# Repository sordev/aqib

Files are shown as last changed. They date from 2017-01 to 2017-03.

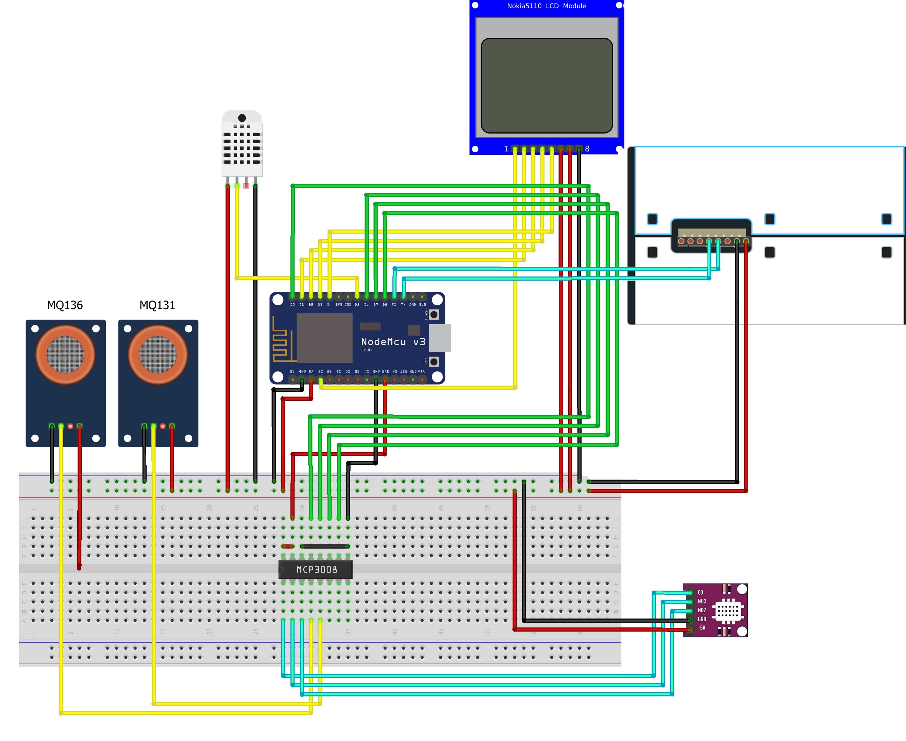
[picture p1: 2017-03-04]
fritzing/aqib_bb.jpg

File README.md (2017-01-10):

# АЧИЛ буюу Агаарын Чанарын Индекс тодорхойлогч Лонх 
(English Readers Please See Below)
АЧИЛ нь агаарын чанарыг тодорхойлох төхөөрөмж бөгөөд хамгийн гол нь хямд зардлаар боломжийн агаарын чанар тодорхойлох төхөөрөмж бий болгохын тулд хийгдсэн. Энэхүү код нь нээлттэй эхийнх ба бусад төрөл бүрийн нээлттэй эхээс жишээ авч бүтээгдсэн болно.

### АЧИЛ нь дараах зүйлсийг тодорхойлно.
  - PM2.5 болон PM10 тоосонцор.
  - SO2, O3, NO2, CO, NH3 химийн нэгдлүүд
  - Орчны температур, чийгшил

### АЧИЛ -н боломжууд.
  - WIFI модуль ашиглан интернэтээр дамжуулан мэдээллээ сервер дээр хадгалах

### Шаардлагатай сэлбэгүүд.
https://docs.google.com/spreadsheets/d/11MSpzdKqcEXNcD25FfU-qca580eOnAqrInOi8nA_Huc/edit?usp=sharing

### АЧИЛ -г бүтээх.
Дараах линкээр орж хэрхэн хийх талаар дэлгэрэнгүй мэдээлэл аваарай.

### Суулгац
Ардиуно https://www.arduino.cc/en/Main/Software -г татан авч ашиглана. Ашиглах сангууд
- Wire.h
- SPI.h
- LiquidCrystal.h
- DHT

### Хэрэглээ
- utaa.mn сайттай холбогдож өөрийн төхөөржийг бүртгүүлж нэвтрэх түлхүүр авна.
- Ардиуно руу байршуулахын өмнө өөрийн ВайФай -н холболтын мэдээлэл болон utaa.mn -с авсан түлхүүрийг оруулж өгнө. Холболт амжилттай хийгдвэл дэлгэц дээр мэдээлэл гарна.
- Төхөөрөмж амжилттай ажиллаж байвал дэлгэц дээр тоон үзүүлэлтүүд харагдах ба харагдаж байгаа тоон үзүүлэлтүүдийг сервер лүү автоматаар илгээж эхлэнэ. Төхөөрөмж нь эхний 24 - 48 цаг сенсор шатаалт явагдах бөгөөд түүнээс хойш үнэн бодит заах магадлалтай болно.

# AQIB Air Quality Index Bottle
AQIB is cheap solution for AQI sensor. Based on arduino and various sensors.

# AQIB can sense following
- PM2.5 and PM10 
- SO2, O3, NO2, CO and NH3 chemicals
- Temperature and humidity

# AQIB Features
- Will collect data and send to main server

# Required PARTS
https://docs.google.com/spreadsheets/d/11MSpzdKqcEXNcD25FfU-qca580eOnAqrInOi8nA_Huc/edit?usp=sharing

# How to build?

# Install
Visit https://www.arduino.cc/en/Main/Software for software. Clone code to your local. Install/Add following librarires
- Wire.h
- SPI.h
- LiquidCrystal.h
- DHT
Compline and upload to Arduino via software.

# Usage
- Ask utaa.mn for API Key
- Change variables inside code with your WiFi connection username/password, Update API Key with your own Key which is provided by utaa.mn
- If AQIB working and connected to WiFi you'll see information on screen, After succesful connection AQIB will show data on screen and will start sending data to server. Sensors requires to be burned out for at least 24-48 hours for good result.

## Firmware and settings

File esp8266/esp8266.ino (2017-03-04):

#include <SPI.h>

// Nokia 5110 LCD Libraries
// https://github.com/baghayi/Nokia_5110
#include "Nokia_5110.h"
#define RST 10 //s3 gpio10
#define CE 5 //d1 gpio5
#define DC 4 //d2 gpio4
#define DIN 0 //d3 gpio0
#define CLK 2 //d3 gpio2
Nokia_5110 lcd = Nokia_5110(RST, CE, DC, DIN, CLK);

// https://www.dfrobot.com/wiki/index.php/PM2.5_laser_dust_sensor_SKU:SEN0177
//******************************
//*Abstract: Read value of PM1,PM2.5 and PM10 of air quality
//
//*Version：V3.1
//*Author：Zuyang @ HUST
//*Modified by Cain for Arduino Hardware Serial port compatibility
//*Date：March.25.2016
//******************************
#include <Arduino.h>
#define LENG 31 //0x42 + 31 bytes equal to 32 bytes
unsigned char buf[LENG];

int PM1Value = 0; //define PM1.0 value of the air detector module
int PM25Value = 0; //define PM2.5 value of the air detector module
int PM10Value = 0; //define PM10 value of the air detector module

#include <ESP8266WiFi.h>
const char ssid[] = "devsor";
const char pass[] = "97070767";
const char api_url[] = "api.utaa.mn";
const char api_key[] = "3aa18dbe7df6844974e199e327c5c30e";
const char unwiredlabs_key[] = "918092cf2502c3";
const int interval = 60000; // 60000 = 1min
unsigned long startTime;
int tries = 0;
byte mac[6];

// Include DHT LIbrary
// DHT Library from https://github.com/adafruit/DHT-sensor-library required https://github.com/adafruit/Adafruit_Sensor
#include <DHT.h>
#define DHTPIN 14 //d5 gpio14
#define DHTTYPE DHT22
DHT dht(DHTPIN, DHTTYPE);
#include <DHT_U.h>
float humidity = 0;
float temp = 0;

// Include mcp3008 library ADC
// https://github.com/nodesign/MCP3008
#include <MCP3008.h>
#define CLOCK_PIN 16 //d0 gpio16
#define MISO_PIN 12 //d6 (mcp3008-Dout) gpio12
#define MOSI_PIN 13 //d7 (mcp3008-Din) gpio13
#define CS_PIN 15 //d8 (mcp3008-CS) gpio15
MCP3008 adc(CLOCK_PIN, MOSI_PIN, MISO_PIN, CS_PIN); //Setup mcp3008

// Analog reads
int co;
int nh3;
int no2;
int so2;
int o3; 

void setup(void)
{
  Serial.begin(9600);
  Serial.setTimeout(1500);    //set the Timeout to 1500ms, longer than the data transmission periodic time of the sensor
  setupSensor();
  ESP.wdtDisable(); // Disable Watchdog
  ESP.wdtEnable(WDTO_8S); // Enabling Watchdog
}

void loop(void)
{
  co = adc.readADC(0);
  nh3 = adc.readADC(1);
  no2 = adc.readADC(2);
  so2 = adc.readADC(3);
  o3 = adc.readADC(4);
  lcd.clear();
  lcd.println("CO: " + (String)co);
  lcd.println("NH3: " + (String)nh3);
  lcd.println("NO2: " + (String)no2);
  lcd.println("SO2: " + (String)so2);
  lcd.println("O3: " + (String)o3);
  delay(2000);

  humidity = dht.readHumidity();
  temp = dht.readTemperature();
  lcd.clear();
  lcd.println("Humi: " + (String)humidity + "%");
  lcd.println("Temp: " + (String)temp + "C");
  delay(2000);

  if (Serial.find(0x42)) {  //start to read when detect 0x42
    Serial.readBytes(buf, LENG);
    if (buf[0] == 0x4d) {
      if (checkValue(buf, LENG)) {
        PM1Value = transmitPM1(buf); //count PM1.0 value of the air detector module
        PM25Value = transmitPM25(buf); //count PM2.5 value of the air detector module
        PM10Value = transmitPM10(buf); //count PM10 value of the air detector module
      }
    }
  }

  lcd.clear();
  lcd.println("PM in ug/m3");
  lcd.println(" ");
  lcd.println("PM 1.0: " + (String)PM1Value);
  lcd.println("PM 2.5: " + (String)PM25Value);
  lcd.println("PM 10: " + (String)PM10Value);
  delay(2000);

  if (WiFi.status() == WL_CONNECTED) {
    //only send data after interval passed
    if (millis()-startTime > interval) {
      updateApi(
      "pm1=" + (String)PM1Value + 
      "&pm25=" + (String)PM25Value + 
      "&pm10=" + (String)PM10Value +       
      "&co=" + (String)co + 
      "&nh3=" + (String)nh3 + 
      "&no2=" + (String)no2 + 
      "&so2=" + (String)so2 + 
      "&o3=" + (String)o3 + 
      "&humidity=" + (String)humidity + 
      "&temperature=" + (String)temp
      );
      // Reset Timer
      startTime = millis();
      delay(3000);
    }
  }

  ESP.wdtFeed(); // Reset the WatchDog
}

boolean connectWiFi() {
  if (WiFi.status() == WL_CONNECTED) {
    lcd.clear();
    lcd.println("Connected WiFi:");
    lcd.println((String)ssid);
    startTime = millis(); // Start counting only when WiFi connected;
    delay(3000);
    return true;
  } else {
    WiFi.begin(ssid, pass);
    while (WiFi.status() != WL_CONNECTED || tries  < 4) {
      tries++;
      lcd.clear();
      lcd.println("Connecting:");
      lcd.println((String)ssid);
      lcd.println("Tries:" + String(tries));
      delay(1000);
    }
    lcd.println("Can't connect:");
    lcd.println((String)ssid);
    delay(2000);
    return false;
  }
}

void setupSensor() {
  lcd.print("Booting Up ...");
  delay(3000);
  connectWiFi();
  if (WiFi.status() == WL_CONNECTED) {
    updateApi("mac=asdasdas&lat=47.921067&lon=106.977267&ip=192.168.1.10");
  }
}

void getIP() {
  // https://api.ipify.org?format=json
}

void getLocation() {
  // https://unwiredlabs.com/api#documentation
  // https://ap1.unwiredlabs.com/v2/process.php
}

void updateApi(String data) {
  WiFiClient client;
  if (client.connect(api_url, 80)) {
    lcd.clear();
    lcd.println("Sending Data");
    data = "api_key=" + (String)api_key + "&" + data;
    client.println("POST /api/update HTTP/1.1");
    client.println("Host: api.utaa.mn");
    //    client.print(api_url);
    client.println("Cache-Control: no-cache");
    client.println("Content-Type: application/x-www-form-urlencoded");
    client.print("Content-Length: ");
    client.println(data.length());
    client.println();
    client.println(data);
  } else {
    lcd.clear();
    lcd.println("Can't Send Data");
    client.stop();
  }
  return;
}

char checkValue(unsigned char *thebuf, char leng)
{
  char receiveflag = 0;
  int receiveSum = 0;
  for (int i = 0; i < (leng - 2); i++) {
    receiveSum = receiveSum + thebuf[i];
  }
  receiveSum = receiveSum + 0x42;
  if (receiveSum == ((thebuf[leng - 2] << 8) + thebuf[leng - 1])) //check the serial data
  {
    receiveSum = 0;
    receiveflag = 1;
  }
  return receiveflag;
}

int transmitPM1(unsigned char *thebuf)
{
  int PM1Val;
  PM1Val = ((thebuf[3] << 8) + thebuf[4]); //count PM1.0 value of the air detector module
  return PM1Val;
}

//transmit PM Value to PC
int transmitPM25(unsigned char *thebuf)
{
  int PM25Val;
  PM25Val = ((thebuf[5] << 8) + thebuf[6]); //count PM2.5 value of the air detector module
  return PM25Val;
}

//transmit PM Value to PC
int transmitPM10(unsigned char *thebuf)
{
  int PM10Val;
  PM10Val = ((thebuf[7] << 8) + thebuf[8]); //count PM10 value of the air detector module
  return PM10Val;
}

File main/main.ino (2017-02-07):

#include <Wire.h>
#include <SPI.h>
// Only if you're using LCD 16x2
#include <LiquidCrystal.h>
// Creates an LC object. Parameters: (rs, enable, d4, d5, d6, d7)
LiquidCrystal lcd(10,9,5,6,7,8);

// Include DHT LIbrary
// DHT Library from https://github.com/adafruit/DHT-sensor-library required https://github.com/adafruit/Adafruit_Sensor
#include <DHT.h>
#define DHTPIN 2
#define DHTTYPE DHT22
DHT dht(DHTPIN, DHTTYPE);
#include <DHT_U.h>

//VARIABLES
byte nano[8] = {B00000,B00000,B00000,B10010,B10010,B10010,B11110,B10000};
byte pow3[8] = {B11000,B00100,B11000,B00100,B11000,B00000,B00000,B00000};

// #include <avr/wdt.h>

#define PM25 0
#define PM10 1
int pin[] = {4,3};
unsigned long starttime;
unsigned long sampletime_ms = 30000;
unsigned long triggerOn[2];
unsigned long triggerOff[2];
unsigned long lowpulseoccupancy[] = {0,0};
float ratio[] = {0,0};
float concentration[] = {0,0};
boolean value[] = {HIGH,HIGH};
boolean trigger[] = {false, false};

float humidity = 0;
float temp = 0;
// If you don't have DHT 11 or DHT 22 uncomment below
// int temp=20; //external temperature, if you can replace this with a DHT11 or better

int so2;
int co;
int nh3;
int no2;

void setup() {
  // Make weird characters
  lcd.createChar(0,nano);
  lcd.createChar(1,pow3);
  // Initializes the interface to the LCD screen, and specifies the dimensions (width and height) of the display }
  lcd.begin(16, 2);
  // DHT Temp humidity sensor begin
  dht.begin();
  // Output to Serial at 9600 baud
  Serial.begin(9600);
  // Start Pin
  pinMode(pin[PM25],INPUT); //Listen at the designated PIN
  pinMode(pin[PM10],INPUT); //Listen at the designated PIN
  // wdt_enable(WDTO_8S);
}

void loop()
{
    lcd.clear();
    // Read mq136 sensor on Analogpin 0
    so2 = analogRead(0);
    // Read 6814 sensor on Analogpin 7,6,5
    co = analogRead(7);
    nh3 = analogRead(6);
    no2 = analogRead(5);

    lcd.print( "SO2: " + (String)so2 );
    lcd.setCursor(9, 0);
    lcd.print( "CO: " + (String)co );
    lcd.setCursor(0, 2);
    lcd.print( "NH3: " + (String)nh3 );
    lcd.setCursor(9, 2);
    lcd.print( "NO2: " + (String)no2 );
    delay(3000);

    lcd.clear(); // Clears the display
    humidity = dht.readHumidity();
    temp = dht.readTemperature();
    lcd.print( "Humi: " + (String)humidity + "%" );
    lcd.setCursor(0, 2);
    lcd.print( "Temp: " + (String)temp + "C");
    delay(3000);

    lcd.clear(); // Clears the display
    lcd.print( "Checking PM");
    lcd.setCursor(0, 2);
    lcd.print( "Wait for 30 sec");
    getPM();
    lcd.clear(); // Clears the display
    lcd.print( "PM10: " + (String)concentration[PM10] );
    lcd.setCursor(0, 2);
    lcd.print( "PM25: " + (String)concentration[PM25] );
    delay(5000);

}

void getPM(){
  // This part is from
  // https://www.shadowandy.net/2015/05/arduino-dust-sensor.htm
  starttime = millis(); //Fetching the current time
  while (1) {
    value[PM25] = digitalRead(pin[PM25]);
    value[PM10] = digitalRead(pin[PM10]);

    if(value[PM25] == LOW && trigger[PM25] == false) {
      trigger[PM25] = true;
      triggerOn[PM25] = micros();
    }
    if(value[PM25] == HIGH && trigger[PM25] == true) {
      triggerOff[PM25] = micros();
      lowpulseoccupancy[PM25] += (triggerOff[PM25] - triggerOn[PM25]);
      trigger[PM25] = false;
    }
    if(value[PM10] == LOW && trigger[PM10] == false) {
      trigger[PM10] = true;
      triggerOn[PM10] = micros();
    }
    if(value[PM10] == HIGH && trigger[PM10] == true) {
      triggerOff[PM10] = micros();
      lowpulseoccupancy[PM10] += (triggerOff[PM10] - triggerOn[PM10]);
      trigger[PM10] = false;
    }

    if ((millis()-starttime) > sampletime_ms)//Checking if it is time to sample
    {
      // main code from https://github.com/empierre/arduino/blob/master/DustSensor_Shinyei_PPD42NS.ino
      // ratio = (lowpulseoccupancy-endtime+starttime)/(sampletime_ms*10.0);  // Integer percentage 0=>100
      // long concentration = 1.1*pow(ratio,3)-3.8*pow(ratio,2)+520*ratio+0.62; // using spec sheet curve
      ratio[PM25] = lowpulseoccupancy[PM25]/(sampletime_ms*10.0);
      concentration[PM25] = 1.1*pow(ratio[PM25],3)-3.8*pow(ratio[PM25],2)+520*ratio[PM25]+0.62;
      ratio[PM10] = lowpulseoccupancy[PM10]/(sampletime_ms*10.0);
      concentration[PM10] = 1.1*pow(ratio[PM10],3)-3.8*pow(ratio[PM10],2)+520*ratio[PM10]+0.62;
      concentration[PM25] -= concentration[PM10];

      // Begin mass ppmv calculation
      temp = dht.readTemperature();
      float ppmv[] = {0,0};
      //ppmv=mg/m3 * (0.08205*Tmp)/Molecular_mass
      //0.08205   = Universal gas constant in atm·m3/(kmol·K)
      ppmv[PM10]=(concentration[PM10]*0.0283168/100/1000)*(0.08205*temp)/0.01;
      ppmv[PM25]=(concentration[PM25]*0.0283168/100/1000)*(0.08205*temp)/0.01;

      // Begin printing to Serial
      Serial.print("PM10 ppmv  : ");
      Serial.print(ppmv[PM10]);
      Serial.println(" ug/m3");
      Serial.print("PM10       : ");
      Serial.print(concentration[PM10]);
      Serial.println(" pt/cf");
      Serial.print("PM2.5 ppmv : ");
      Serial.print(ppmv[PM25]);
      Serial.println(" ug/m3");
      Serial.print("PM2.5      : ");
      Serial.print(concentration[PM25]);
      Serial.println(" pt/cf");
      Serial.println("");

      // Resetting for next sampling
      lowpulseoccupancy[PM25] = 0;
      lowpulseoccupancy[PM10] = 0;
      // starttime = millis();
      return;
    }
  }
}

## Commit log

2017-02-07 Final update. Works with all sensors and LCD screen.
2017-03-01 Fix on serial, api data populated
    [esp8266.ino]
2017-03-04 cable management inclusion of mcp3008 ADC
2017-03-04 fritzing images
    [aqib.fzz]
2017-03-04 not sure what changed
    [aqib.fzz]
